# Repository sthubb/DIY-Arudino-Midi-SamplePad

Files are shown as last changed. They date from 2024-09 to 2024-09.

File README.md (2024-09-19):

# DIY-Arudino-Midi-SamplePad
이 페이지는 아두이노 레오나르도 보드와 피에조 센서를 이용해 샘플링 드럼패드를 직접 제작하고 개발하는 과정을 서술합니다
<br>

# 만들게 된 계기
  * 기성품 드럼 샘플링 패드들이 전부 50만원대 이상으로 매우 비싸다
  * 그닥 기능도 없는거같은데 어이가 없어서.
    
# 사용된 부품

  * **아두이노 레오나르도** (혹은 ATmega32U4 칩을 사용하며 아날로그 인풋이 6개 이상 가지고 있는 모든 마이크로 컨트롤러) x1
  * **16x2 LCD** (I2C모듈 포함) x1
  * **피에조 센서** x6
  * 1M옴 저항 x6
  * 배선재 
  * 빵판 (권장)

# 회로도 설명
스크린샷 2024-09-04 오후 4 43 47

<br>
<br>

> 본 가이드는 ATmega32u4칩을 내장한 아두이노 레오나르도 기준으로 서술합니다

* 아두이노 우노같은 일반적인 ATmega328P칩셋은 시리얼 신호만 출력하기에 미디 신호를 받으려면 시리얼 신호를 미디로 변환해주는 별도의 프로그램이 필요합니다. 가능하면 레오나르도같이 ATmega32u4칩셋을 사용하는 보드를 사용하세요.
* 회로도 잘못만들어서 LCD 그라운드가 연결되어있지 않습니다.. 참고하여 4개의 핀들 모두 잘 연결해주세요

# 작동 원리
* 아두이노가 피에조 센서의 측정값을 정수로 입력
* 센서 측정값이 threshold 값보다 크고, 이전 음표보다 debounceTime만큼 지났는지 체크하여 중복 입력 방지
* MIDIUSB 라이브러리를 이용하여 미디 값을 전송
* LCD에 패드 번호 (핀번호와 일치함)와 음표 값을 표시 (ex. Pad: 1, Note: C1)

# 하드웨어 제작
스크린샷 2024-09-19 오전 11 21 48
<br>

* 3D프린트된 베이스에 아크릴 상판을 덮는 형식으로 제작했습니다. 제작하기 위해선 최소 240x190x200mm 사이즈로 출력이 가능한 3D 프린터와 아크릴을 자를 레이저 커팅기가 필요합니다.
<br>

스크린샷 2024-09-19 오전 11 41 54
<br>

* 각자 패드는 이미지와 같은 방진 구조를 가지고 있습니다. 다른 디자인으로 제작해도 좋지만 진동이 너무 잘 전달되게 되면 피에조 센서에 간섭이 생겨서 다른 노트들이 입력되는 현상이 생길수 있습니다.
<br>

# 제작 과정





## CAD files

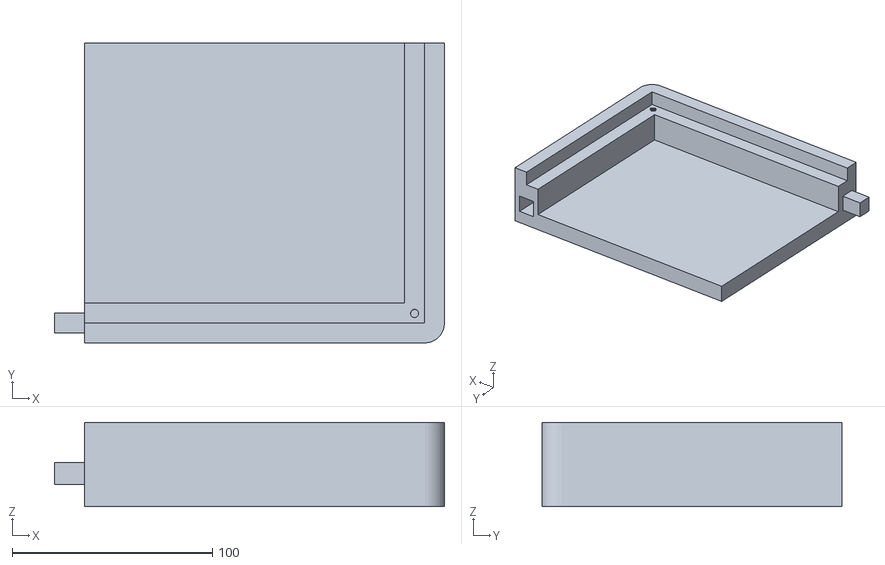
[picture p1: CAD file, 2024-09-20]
3D Print Files/Part2.stl
195.0 x 150.0 x 42.0

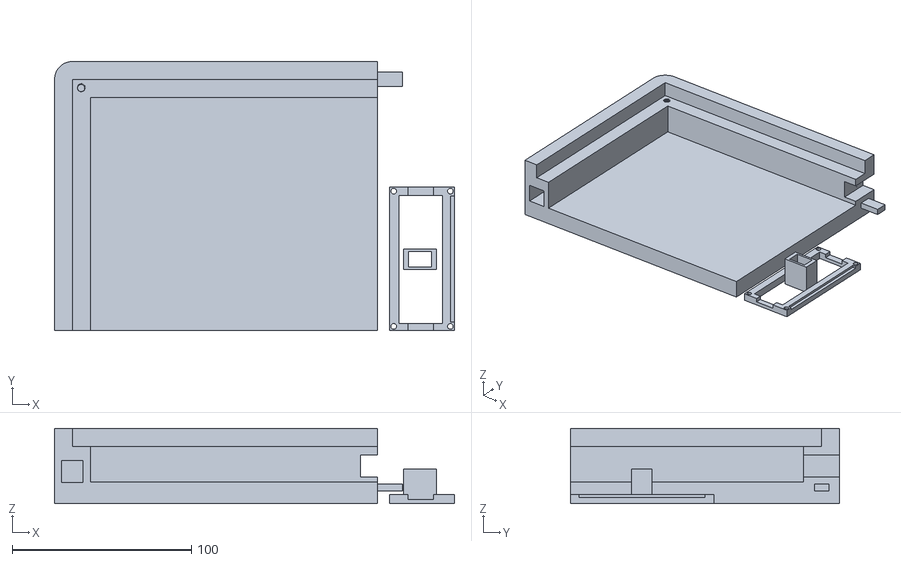
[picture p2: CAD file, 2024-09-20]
3D Print Files/Part4.stl
223.0 x 150.0 x 42.0

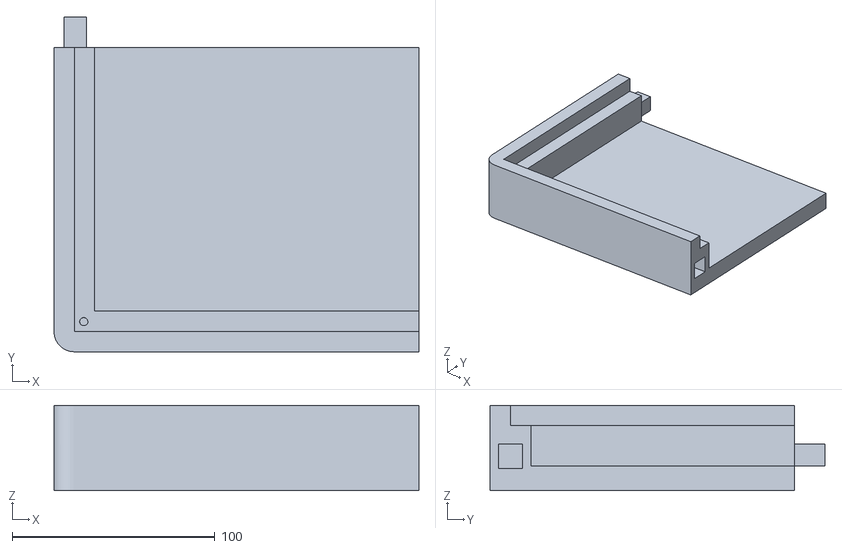
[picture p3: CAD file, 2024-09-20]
3D Print Files/Part1.stl
180.0 x 165.0 x 42.0

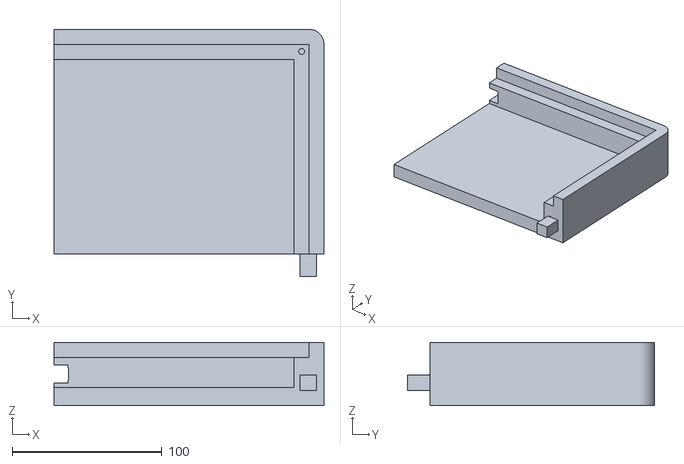
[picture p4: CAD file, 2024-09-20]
3D Print Files/Part3.stl
180.0 x 165.0 x 42.0

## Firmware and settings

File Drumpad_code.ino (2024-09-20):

#include <MIDIUSB.h>
#include <Wire.h>
#include <LiquidCrystal_I2C.h>

// Set the LCD address to 0x27 for a 16x2 display
LiquidCrystal_I2C lcd(0x27, 16, 2);

const int threshold = 500;  // Minimum value to trigger a note
const int debounceTime = 50; // Debounce time in milliseconds
const int noiseDelayTime = 2000;  // Delay for initial noise stabilization (2 seconds)

// Pin assignments for piezo sensors
const int piezoPins[6] = {A0, A1, A2, A3, A4, A5};
// MIDI note assignments
const int midiNotes[6] = {42, 44, 46, 36, 38, 37};  // C1, D1, C#1, F#1, G#1, A#1
// MIDI note names
const char* noteNames[6] = {"C1", "D1", "C#1", "F#1", "G#1", "A#1"};

// Store the last trigger time to debounce pads
unsigned long lastTriggerTime[6] = {0, 0, 0, 0, 0, 0};

void setup() {
  // Initialize Serial communication for serial monitor output
  Serial.begin(9600);

  for (int i = 0; i < 6; i++) {
    pinMode(piezoPins[i], INPUT);
  }

  // Initialize the LCD
  lcd.init();
  lcd.backlight();

  // Display a startup message
  lcd.setCursor(0, 0);
  lcd.print("Drum Pad Ready!");
  
  // Wait for noise stabilization
  delay(noiseDelayTime);
}

void loop() {
  for (int i = 0; i < 6; i++) {
    int sensorValue = analogRead(piezoPins[i]);

    // Trigger only if value is above threshold and debounce time has passed
    if (sensorValue > threshold && millis() - lastTriggerTime[i] > debounceTime) {
      sendMIDI(midiNotes[i]);
      displayPadInfo(i); // Display pad number and MIDI note on LCD
      printPadInfoToSerial(i); // Print pad info to Serial Monitor
      lastTriggerTime[i] = millis();
    }
  }
}

// Function to send MIDI note
void sendMIDI(byte note) {
  midiEventPacket_t noteOn = {0x09, 0x90, note, 127};  // 127 velocity, note ON
  MidiUSB.sendMIDI(noteOn);
  MidiUSB.flush();

  midiEventPacket_t noteOff = {0x08, 0x80, note, 0};   // note OFF
  delay(10);  // Short delay for note off
  MidiUSB.sendMIDI(noteOff);
  MidiUSB.flush();
}

// Function to display the pad number and MIDI note on the LCD
void displayPadInfo(int padIndex) {
  lcd.clear();
  lcd.setCursor(0, 0);
  lcd.print("Pad: ");
  lcd.print(padIndex + 1);  // Display pad number (1 to 6)
  
  lcd.setCursor(0, 1);
  lcd.print("Note: ");
  lcd.print(noteNames[padIndex]);  // Display MIDI note name (C1, D1, etc.)
}

// Function to print pad info to Serial Monitor
void printPadInfoToSerial(int padIndex) {
  Serial.print("Pad: ");
  Serial.print(padIndex + 1);  // Print pad number (1 to 6)
  Serial.print(" | Note: ");
  Serial.println(noteNames[padIndex]);  // Print MIDI note name (C1, D1, etc.)
}
